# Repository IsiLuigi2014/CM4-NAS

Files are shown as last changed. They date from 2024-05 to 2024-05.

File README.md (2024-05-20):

# CM4 NAS Board [UNMAINTAINED | UNTESTED]

This is a fork from the CM4 NAS Board Project from mebs, added 12V power circuitry only to power it. UNTESTED

This Compute Module 4 carrier board design exposes a subset of the CM4's interfaces, including its single PCIe 2.0 lane to accept an external SATA controller card.
This design is based off of the official Raspberry Pi Foundation's CM4 IO board (the KiCad project is available on the [IO board official page](https://www.raspberrypi.org/products/compute-module-4-io-board/?resellerType=home)). Removed the IO that was less relevant for a NAS and rearranged the remaining interfaces for a smaller footprint that would fit within the width of a standard 3.5" hard drive.

The board was intentionally kept simple to limit mistakes as this is my first ever attempt at designing a PCB and I have no background in electronics, so all the power management is left to external power supplies and buck converters. It's important to use good quality regulated power supplies with this board as it offers no protection other than what is built into the CM4.

Also made 3D printed enclosure for the final product. Design available here: https://www.thingiverse.com/thing:4820662 (Properly not compertablie anymore since made board bigger for 12v power only)

Feel free to explore the discussion section of this repo to share ideas.

[Latest Reddit post here.](https://www.reddit.com/r/raspberry_pi/comments/mkbxss/cm4_custom_nas_complete/)



##### Table of Contents
- [Software](#software)
- [Board IO](#board-io)
  * [CM4 IO Breakout](#cm4-io-breakout)
  * [Other Connections on the Board](#other-connections-on-the-board)
- [PCB Assembly](#pcb-assembly)
  * [Manufacturing](#manufacturing)
  * [Required Parts](#required-parts)
  * [Building](#building)
- [Pinout](#pinout)
- [Revision History](#revision-history)

# Software
For the software part of this project, I highly recommend [Jeff Geerling's repo](https://github.com/geerlingguy/raspberry-pi-pcie-devices/issues), where he documented similar endeavors, but you will likely have to recompile the kernel after enabling some modules to be able to use a PCIe SATA controller.

Don't hesitate to ask questions in the Discussion tab of this repo.

# Board IO
## CM4 IO Breakout
The interfaces the board forwards from the CM4 are the following:
- **PCIe x1 Gen2**: Good old PCIe 2.0, nothing special about it... if not that it's on a Raspberry Pi.
- **Ethernet**: To reduce the number of components on the board and make assembly easier, a MagJack is used instead of a simple RJ45 connector. I had to look this up when I saw it in the IO board design, but a MagJack seems to be simply an RJ45 connector with integrated filters to help with signal integrity. Footprint is specific to the part listed bellow.
- **Single master/slave USB, selected with jumper**: A USB type A port to plug a keyboard, a flash drive, a hub, or whatever you want to use as a USB slave to the CM4. Footprint is not standard so make sure it fits yours if you manufacture the PCB. Can also be used in slave mode (CM4 as slave). You would use this to program the eMMC with you computer. This connection taps into the same single USB bus the CM4 has to offer, but when this is used, the VCC input from the master signals that the CM4 should behave as a slave. Currently the footprint for this is a simple 5 pin header.
- **Full size HDMI**:  Mostly for debugging purposes, hooked to the HDMI0 output of the CM4.
- **I²C**: This is marked "OLED" on the board because this was the intended use, but you can use this to slave any I²C device to the CM4. Five-pin JST connector footprint (fits simple headers too).
- **Single wire temperature sensor**: Marked "Temp_sensor" on the board, hooked to GPIO_4 on the CM4. I would recommend using it for a temp sensor near the SATA controller because they can get really hot and control the fan (see bellow) based on that.
- **9 GPIOs**: General purpose IO header, including Gnd, 3V3 and 5V pins.
- **Configuration headers**: nRPIBOOT, EEPROM_nWP, AIN1, SYNC_IN, SYNC_OUT, TV_OUT, GLOBAL_EN, RUN_PG, WL_nDis, BT_nDis. The pinout is detailed on the board.

## Other Connections on the Board
Other than relaying the compute module's IOs, the board adds other connections, mainly for power.
- **Fan control**: The board expects a dedicated PWM fan controller IC (see part list). Its output is routed to this JST connector (or your typical PWM fan connector) marked "Fan_PWM" on the board.
- **USB selection headers**: To avoid needing a USB MUX on board, this header should be used with a jumper to select if you want to use the USB bus as master or as slave.
- **HDDs power**: Labeled "SATA_PWR". This is the power rail for the hard drives.

# PCB Assembly
## Manufacturing
There is a *Fab* folder at the repo's root. This folder contains all the files that you need to order PCBs from a manufacturer. You will find in the folder a Fab_rev1.4.zip archive that is all you need to order from JLC PCB. This is the latest version and the one I have been running for months now.

## Required Parts
Other than the standard caps and resistors, here are the components you will need if you want to assemble the board:
- **High density connectors** ([digikey](https://www.digikey.ca/en/products/detail/hirose-electric-co-ltd/DF40C-100DS-0.4V%2851%29/1969495), [LCSC](https://lcsc.com/product-detail/Mezzanine-Connectors-Board-to-Board_HRS-Hirose-DF40C-100DS-0-4V-51_C597931.html)): You will need these to connect the CM4 to the board. They can be very daunting, but I found [this video](https://www.youtube.com/watch?v=eukcrFc18P4) of someone neatly soldering them with a hot air gun. When I finaly got to try it, I was surprise at how doable it was.
- **Ethernet** ([digikey](https://www.digikey.de/de/products/detail/abracon-llc/ARJM11C7-502-AB-ER2-T/7675199)): Switch from the expensive one to a cheaper model.
- **Fan controller** ([digikey](https://www.digikey.ca/en/products/detail/microchip-technology/EMC2301-1-ACZL-TR/4696431), [LCSC](https://lcsc.com/product-detail/_MICROCHIP_EMC2301-1-ACZL-TR_EMC2301-1-ACZL-TR_C148036.html)): This chip is the exact same one that is on the official IO board and it's controlled by the CM4 through I²C.
- **ESD sinks** ([digikey](https://www.digikey.ca/en/products/detail/texas-instruments/TPD4EUSB30DQAR/2503671), [LCSC](https://lcsc.com/product-detail/Diodes-ESD_Texas-Instruments-TPD4EUSB30DQAR_C90627.html)): They are optional in my (very uninformed) opinion. I think they were included on the IO board for POE applications mostly.
- **Signal buffer** ([digikey](https://www.digikey.ca/en/products/detail/diodes-incorporated/74LVC1G07SE-7/2356550), [LCSC](https://lcsc.com/product-detail/Logic-Buffers-Drivers-Receivers-Transceivers_Diodes-Incorporated-74LVC1G07SE-7_C67531.html)): Used for the power LED and to buffer RUN_PG signal to be able to wake the CM4 from a sleep state.
- **HDMI connector** ([LCSC](https://lcsc.com/product-detail/Audio-Video-Connectors_SOFNG-HDMI-019S_C111617.html)): Basic full size HDMI connector.

## Building
To build the board, you will need a soldering iron and a hot air gun (or a reflow oven). I would recommend starting with the Hirose high density connectors as they are without a doubt the hardest part. [This video](https://www.youtube.com/watch?v=eukcrFc18P4) I referred to earlier is a good starting point, it makes for a fine tutorial.
It only took a couple tries before I could get a decent result (image from microscope at around 50-60x):



Once the HD connectors are in place, you can move on to the ESD sinks. They are very small and can also be daunting, but soldering them turned out to be easier than expected.
The trick is to put as little solder paste as possible and the chips will naturally be pulled in place by the solder's surface tension.



The rest of the parts should be fairly easy to solder with a standard iron.

# Pinout
**Not up to date anymore.**

  

# Revision History
- **1**: Initial version
- **1.1**: Fixed wrong footprint for fan controller
- **1.2**: Changed the USB select headers for a simpler solution with a single jumper
- **1.3**: Replaced the HDMI header by a full size HDMI female connector, exposed 9 GPIOs, inverted polarity back for PCIe Tx/Rx signals and added a power LED.
- **1.4**: Add pin to OLED connector for button, use SMD caps and LEDs, more info on silkscreen and fixed some traces.
- **1.5**: Added support for 12v power only

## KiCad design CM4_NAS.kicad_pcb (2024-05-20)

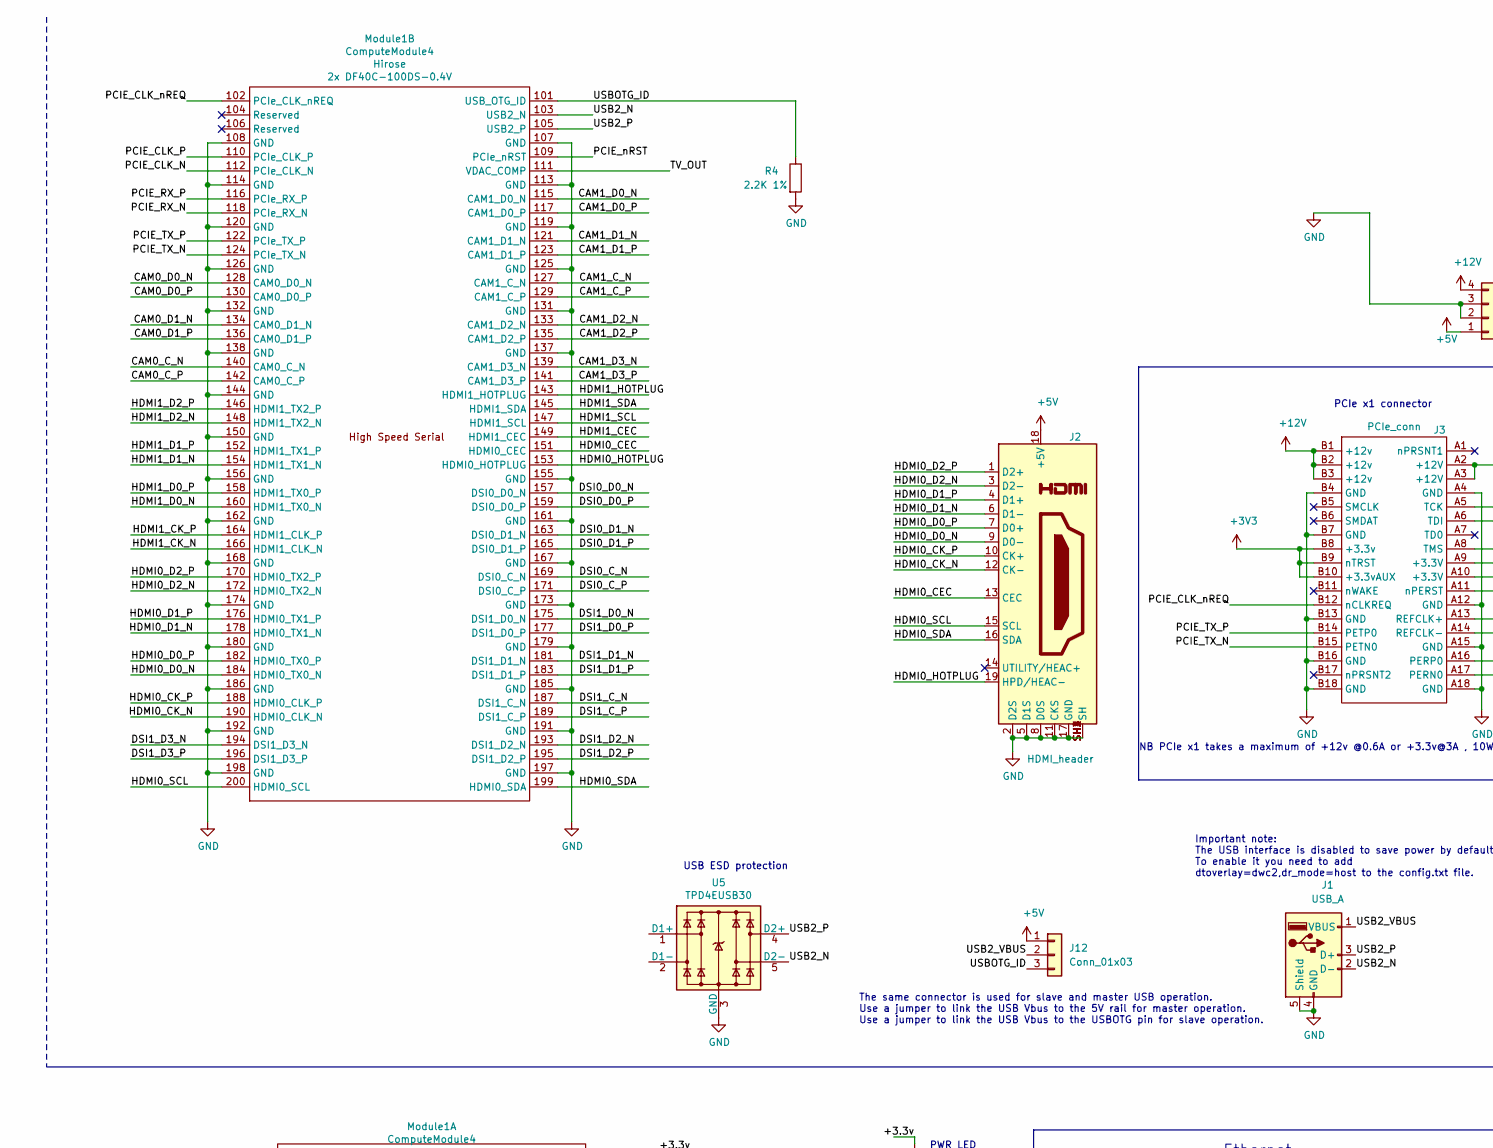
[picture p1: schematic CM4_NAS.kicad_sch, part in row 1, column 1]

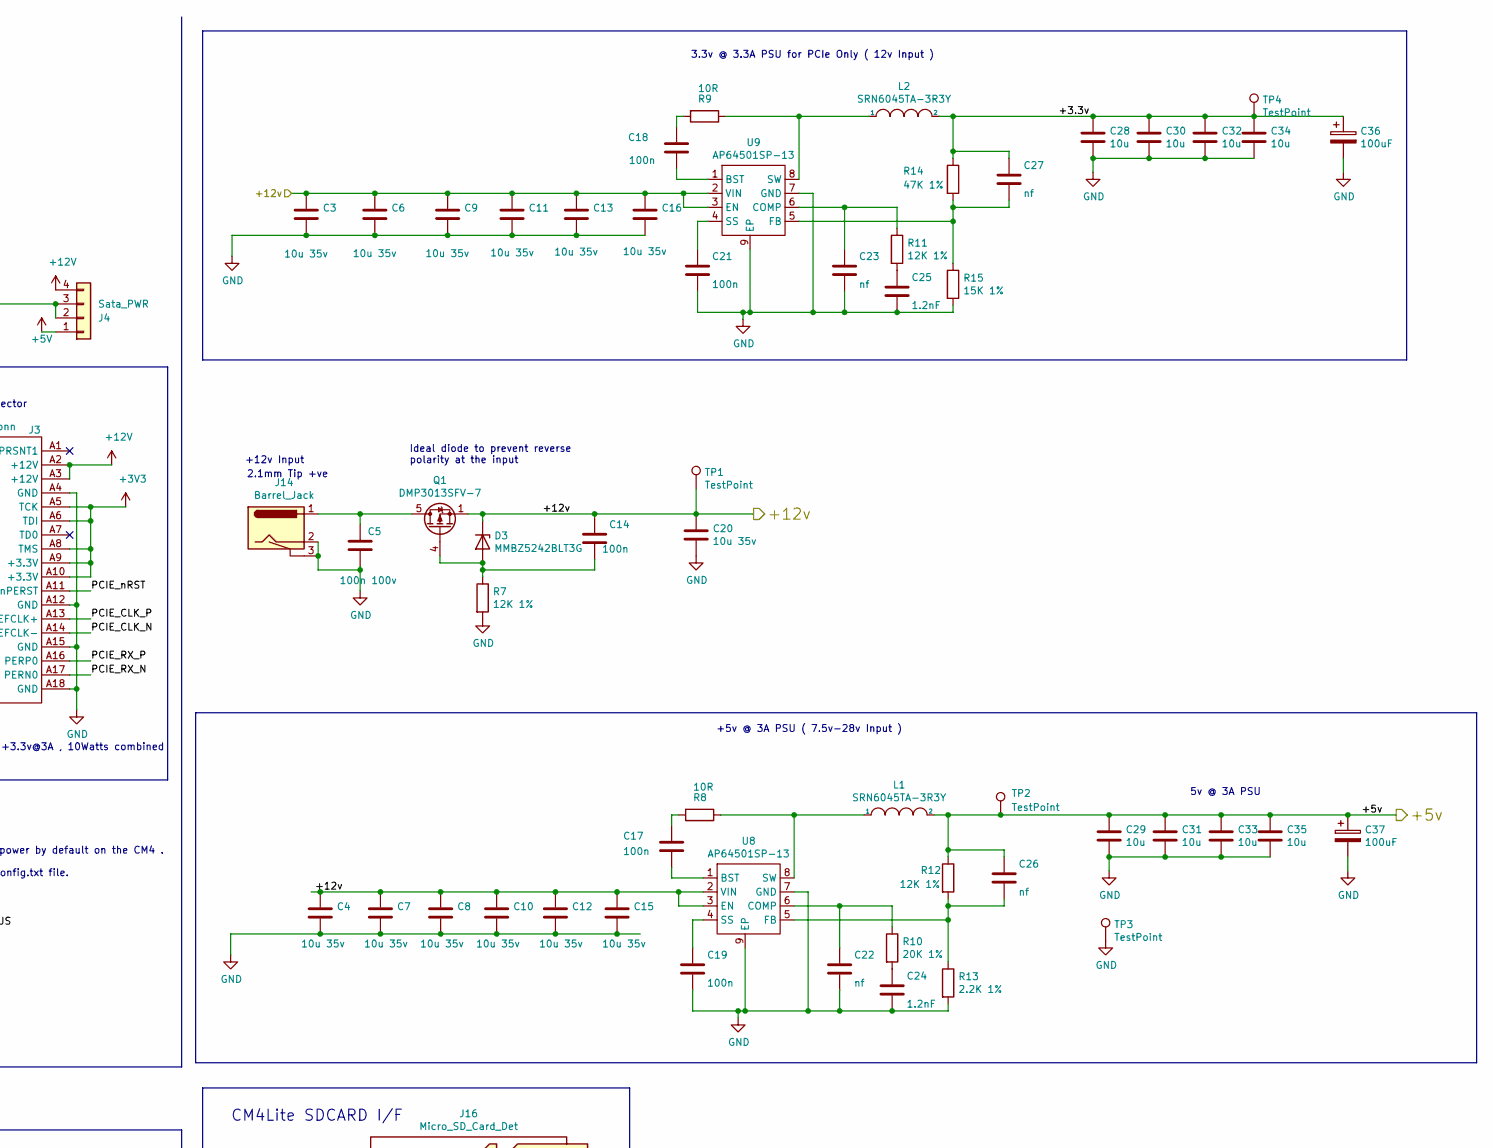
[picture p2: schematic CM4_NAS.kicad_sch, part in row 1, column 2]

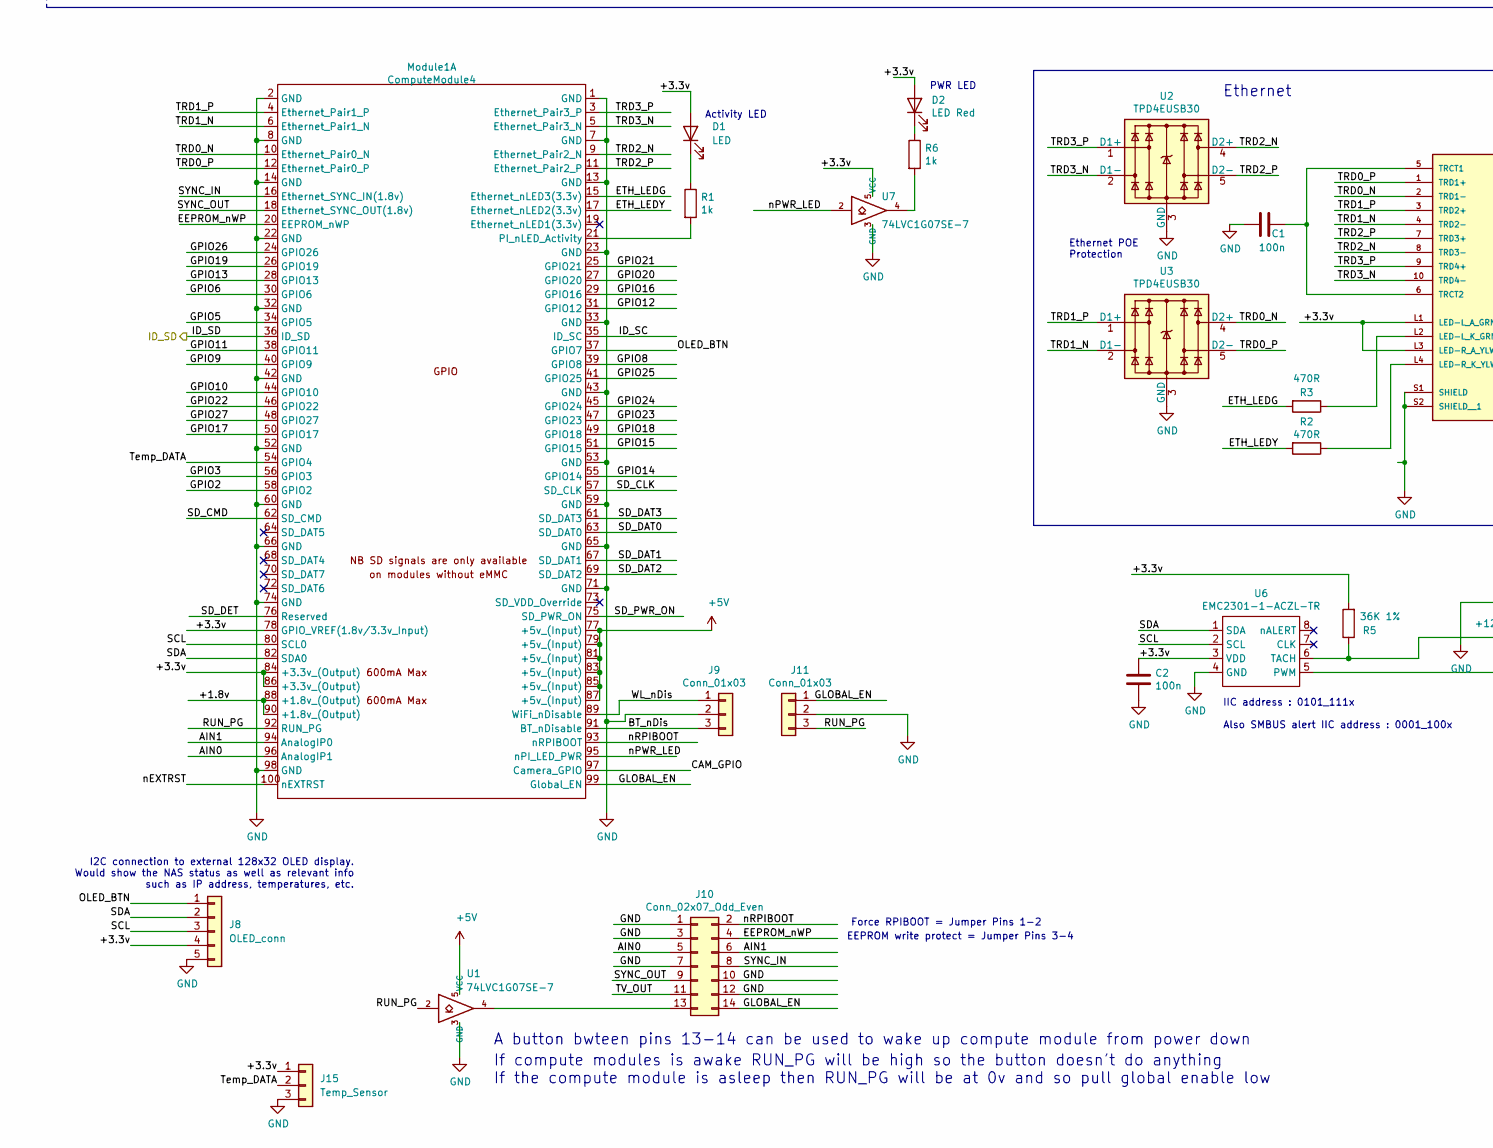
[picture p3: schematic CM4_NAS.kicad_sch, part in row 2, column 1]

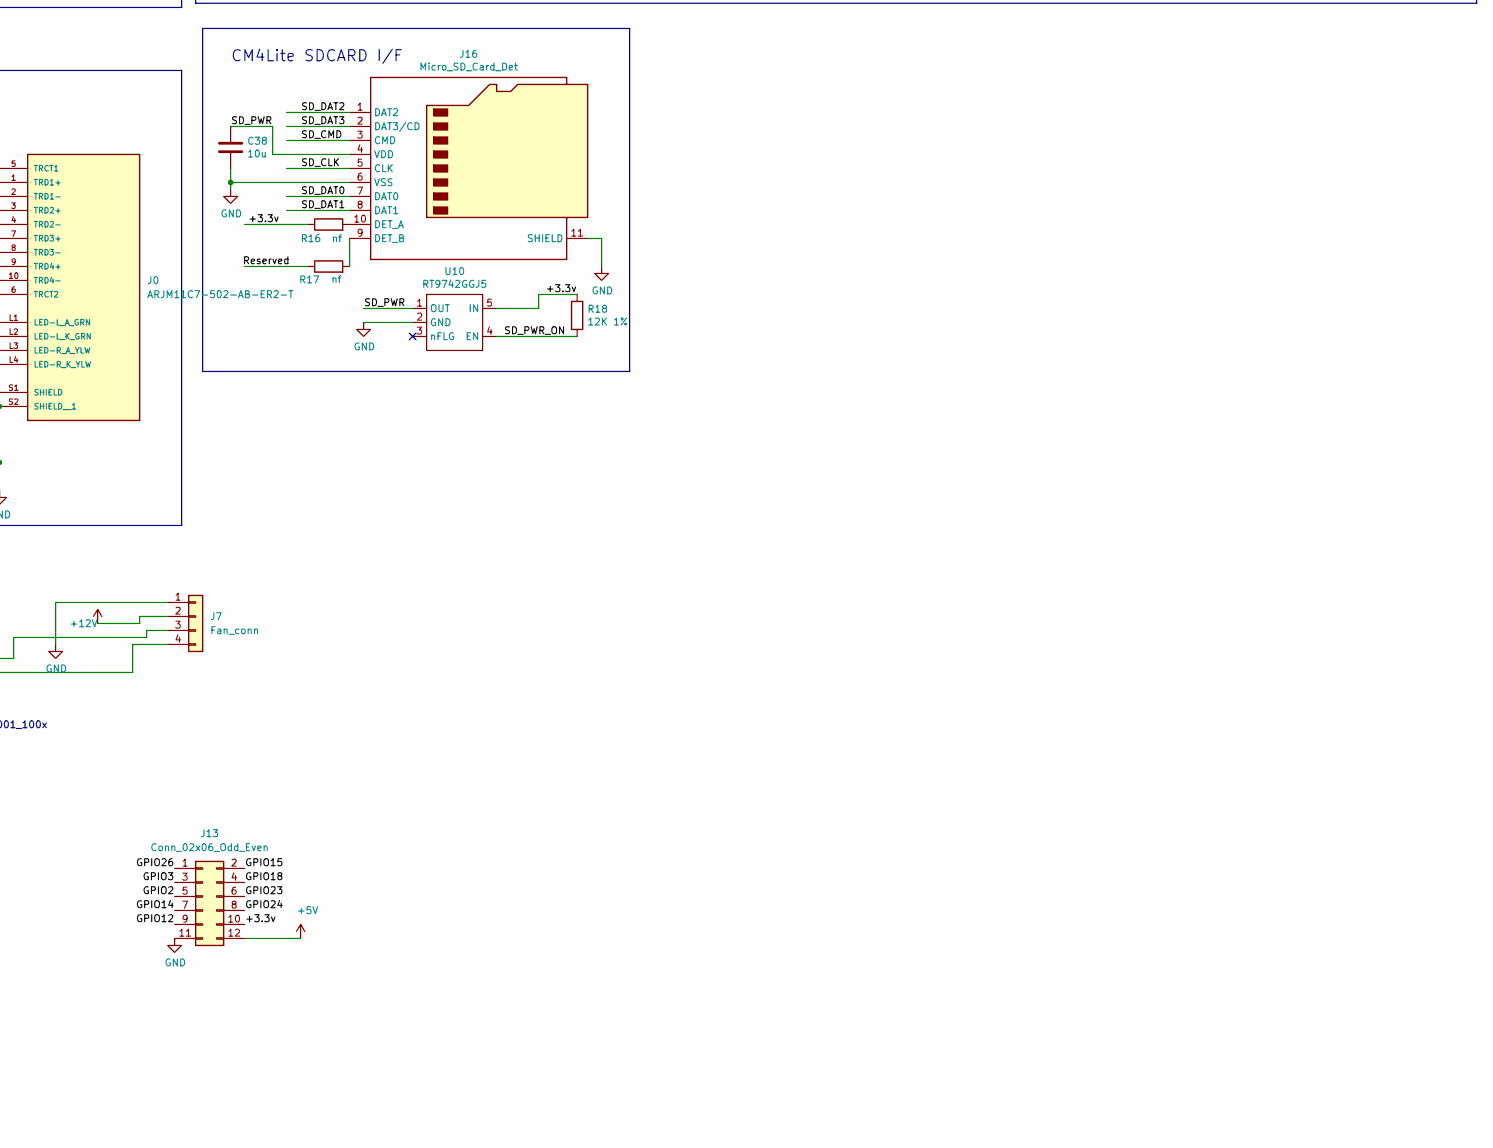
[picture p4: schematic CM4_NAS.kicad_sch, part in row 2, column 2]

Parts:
C1, C2: 100n; C_0805_2012Metric_Pad1.18x1.45mm_HandSolder
C3, C4, C6, C7, C8, C9, C10, C11, C12, C13, C15, C16, C20: 10u 35v; C_0805_2012Metric; Part Description 10uF 10% or 20% 35V Ceramic Capacitor X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
C5: 100n 100v; C_0402_1005Metric; Part Description 0.1uF 10% 100V Ceramic Capacitor X5R 04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
C14, C17, C18, C19, C21: 100n; C_0402_1005Metric; Part Description 0.1uF 10% 16V Ceramic Capacitor X7R 040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
C22, C23: nf; C_0402_1005Metric
C24, C25: 1.2nF; C_0402_1005Metric; Part Description 1200pF 10% 10V Ceramic Capacitor X5R 04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
C26: nf; C_0402_1005Metric; Part Description 220 pF, 50 V, 0402 [1005 Metric], ± 5%,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
C27: nf; C_0402_1005Metric; Part Description 27pF 5% 50V Ceramic Capacitor C0G, NP0 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
C28, C29, C30, C31, C32, C33, C34, C35, C38: 10u; C_0805_2012Metric; Part Description 10uF 10% 10V Ceramic Capacitor X7R 0805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
C36, C37: 100uF; CP_EIA-7343-31_Kemet-D; Part Description Capacitor, SP-Cap, 100u, 6.3V, 15mR ESR
D1: LED; LED_0805_2012Metric_Pad1.15x1.40mm_HandSolder
D2: LED Red; LED_0805_2012Metric_Pad1.15x1.40mm_HandSolder
D3: MMBZ5242BLT3G; D_SOT-23_ANK; Part Description Zener Diode 12V 225mW 5% Surface Mount 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
J0: ARJM11C7-502-AB-ER2-T; ABRACON_ARJM11C7-502-AB-ER2-T; PARTREV 04.22.2019
J1: USB_A; USB_A_Vertical
J2: HDMI_header; HDMI EDAC 690-019-298-412
J3: PCIe_conn; PCIex1-36; Part Description PCI Express/PCI Connectors PCIE THROUGH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
J4: Sata_PWR; JST_XH_B4B-XH-A_1x04_P2.50mm_Vertical
J7: Fan_conn; JST_XH_B4B-XH-A_1x04_P2.50mm_Vertical
J8: OLED_conn; JST_XH_B5B-XH-A_1x05_P2.50mm_Vertical
J9, J11: Conn_01x03; PinHeader_1x03_P2.54mm_Vertical; Part Description 3pin 0.1" connector
J10: Conn_02x07_Odd_Even; PinHeader_2x07_P2.54mm_Vertical; Part Description PinHeader_2x07_P2.54mm_Vertical
J12: Conn_01x03; PinHeader_1x03_P2.54mm_Vertical
J13: Conn_02x06_Odd_Even; PinHeader_2x06_P2.54mm_Vertical
J14: Barrel_Jack; BarrelJack_Horizontal; Part Description DC Power Connectors PCB 2.1MM
J15: Temp_Sensor; PinSocket_1x03_P2.54mm_Vertical
J16: Micro_SD_Card_Det; SDCARD_MOLEX_503398-1892; Part Description 9 (8 + 1) Position Card Connector micro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
L1, L2: SRN6045TA-3R3Y; L_Bourns_SRN6045TA; Part Description 3.3µH Semi-Shielded Wirewound Inductor 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
Module1: ComputeModule4; Raspberry-Pi-4-Compute-Module; Part Description 100 Position Connector Receptacle, Cent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
Q1: DMP3013SFV-7; Diodes_PowerDI3333-8; Part Description DMP3013SFV-7 - Power MOSFET, P Channel,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
R1, R6: 1k; R_0402_1005Metric; Part Description Resistor 1K M1005 1% 63mW
R2: 470R; R_0402_1005Metric
R3: 470R; R_0402_1005Metric; Part Description Resistor 470R M1005 1% 63mW
R4: 2.2K 1%; R_0402_1005Metric
R5: 36K 1%; R_0402_1005Metric
R7, R11, R12, R18: 12K 1%; R_0402_1005Metric; Part Description Resistor 12K M1005 1% 63mW
R8, R9: 10R; R_0402_1005Metric; Part Description Resistor 10R M1005 1% 63mW
R10: 20K 1%; R_0402_1005Metric; Part Description Resistor 20K M1005 1% 63mW
R13: 2.2K 1%; R_0402_1005Metric; Part Description Resistor 2.2K M1005 1% 63mW
R14: 47K 1%; R_0402_1005Metric; Part Description Resistor 47K M1005 1% 63mW
R15: 15K 1%; R_0402_1005Metric; Part Description Resistor 15K M1005 1% 63mW
R16, R17: nf; R_0402_1005Metric; Part Description Resistor 1K M1005 1% 63mW
TP1, TP2, TP3, TP4: TestPoint; TestPoint_Pad_2.0x2.0mm
U1, U7: 74LVC1G07SE-7; SOT-353_SC-70-5; Part Description Buffer, Non-Inverting 1 Element 1 Bit p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
U2, U3, U5: TPD4EUSB30; USON-10_2.5x1.0mm_P0.5mm; Part Description Quad TVS diode for high speed signals (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
U6: EMC2301-1-ACZL-TR; MSOP-8_3x3mm_P0.65mm; Part Description Motor Driver PWM 8-MSOP
U8, U9: AP64501SP-13; SOIC-8-1EP_3.9x4.9mm_P1.27mm_EP2.95x4.9mm_Mask2.71x3.4mm_Th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; Part Description Buck Switching Regulator IC Positive Ad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
U10: RT9742GGJ5; SOT-23-5; Part Description Power Switch/Driver 1:1 N-Channel 1A TS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

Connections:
+3V3: J3.A5 (TCK), J3.A6 (TDI), J3.A8 (TMS), J3.A9 (+3.3V), J3.A10 (+3.3V), J3.B8 (+3.3v), J3.B9 (nTRST), J3.B10 (+3.3vAUX)
+5V: J2.18 (+5V), J4.1, J12.1, J13.12, Module1.77 (+5v_(Input)), Module1.79 (+5v_(Input)), Module1.81 (+5v_(Input)), Module1.83 (+5v_(Input)), Module1.85 (+5v_(Input)), Module1.87 (+5v_(Input)), U1.5 (VCC)
+12V: J3.A2 (+12V), J3.A3 (+12V), J3.B1 (+12v), J3.B2 (+12v), J3.B3 (+12v), J4.4, J7.2
/+1.8v: Module1.88 (+1.8v_(Output)), Module1.90 (+1.8v_(Output))
/+3.3v: C2.1, C27.1, C28.1, C30.1, C32.1, C34.1, C36.1, D1.2 (A), D2.2 (A), J0.L1 (LED-L_A_GRN), J0.L3 (LED-R_A_YLW), J8.4, J13.10, J15.1, L2.2, Module1.78 (GPIO_VREF(1.8v/3.3v_Input)), Module1.84 (+3.3v_(Output)), Module1.86 (+3.3v_(Output)), R5.2, R14.1, R16.1, R18.1, TP4.1, U6.3 (VDD), U7.5 (VCC), U10.5 (IN)
/+5v: C26.1, C29.1, C31.1, C33.1, C35.1, C37.1, L1.2, R12.1, TP2.1
/+12v: C3.1, C4.1, C6.1, C7.1, C8.1, C9.1, C10.1, C11.1, C12.1, C13.1, C14.1, C15.1, C16.1, C20.1, D3.1 (K), Q1.1 (S), Q1.2 (S), Q1.3 (S), TP1.1, U8.2 (VIN), U8.3 (EN), U9.2 (VIN), U9.3 (EN)
/AIN0: J10.5, Module1.96 (AnalogIP1)
/AIN1: J10.6, Module1.94 (AnalogIP0)
/BT_nDis: J9.3, Module1.91 (BT_nDisable)
/CAM0_C_N: Module1.140 (CAM0_C_N)
/CAM0_C_P: Module1.142 (CAM0_C_P)
/CAM0_D0_N: Module1.128 (CAM0_D0_N)
/CAM0_D0_P: Module1.130 (CAM0_D0_P)
/CAM0_D1_N: Module1.134 (CAM0_D1_N)
/CAM0_D1_P: Module1.136 (CAM0_D1_P)
/CAM1_C_N: Module1.127 (CAM1_C_N)
/CAM1_C_P: Module1.129 (CAM1_C_P)
/CAM1_D0_N: Module1.115 (CAM1_D0_N)
/CAM1_D0_P: Module1.117 (CAM1_D0_P)
/CAM1_D1_N: Module1.121 (CAM1_D1_N)
/CAM1_D1_P: Module1.123 (CAM1_D1_P)
/CAM1_D2_N: Module1.133 (CAM1_D2_N)
/CAM1_D2_P: Module1.135 (CAM1_D2_P)
/CAM1_D3_N: Module1.139 (CAM1_D3_N)
/CAM1_D3_P: Module1.141 (CAM1_D3_P)
/CAM_GPIO: Module1.97 (Camera_GPIO)
/DSI0_C_N: Module1.169 (DSI0_C_N)
/DSI0_C_P: Module1.171 (DSI0_C_P)
/DSI0_D0_N: Module1.157 (DSI0_D0_N)
/DSI0_D0_P: Module1.159 (DSI0_D0_P)
/DSI0_D1_N: Module1.163 (DSI0_D1_N)
/DSI0_D1_P: Module1.165 (DSI0_D1_P)
/DSI1_C_N: Module1.187 (DSI1_C_N)
/DSI1_C_P: Module1.189 (DSI1_C_P)
/DSI1_D0_N: Module1.175 (DSI1_D0_N)
/DSI1_D0_P: Module1.177 (DSI1_D0_P)
/DSI1_D1_N: Module1.181 (DSI1_D1_N)
/DSI1_D1_P: Module1.183 (DSI1_D1_P)
/DSI1_D2_N: Module1.193 (DSI1_D2_N)
/DSI1_D2_P: Module1.195 (DSI1_D2_P)
/DSI1_D3_N: Module1.194 (DSI1_D3_N)
/DSI1_D3_P: Module1.196 (DSI1_D3_P)
/EEPROM_nWP: J10.4, Module1.20 (EEPROM_nWP)
/ETH_LEDG: Module1.15 (Ethernet_nLED3(3.3v)), R3.2
/ETH_LEDY: Module1.17 (Ethernet_nLED2(3.3v)), R2.2
/GLOBAL_EN: J10.14, J11.1, Module1.99 (Global_EN)
/GPIO2: J13.5, Module1.58 (GPIO2)
/GPIO3: J13.3, Module1.56 (GPIO3)
/GPIO5: Module1.34 (GPIO5)
/GPIO6: Module1.30 (GPIO6)
/GPIO8: Module1.39 (GPIO8)
/GPIO9: Module1.40 (GPIO9)
/GPIO10: Module1.44 (GPIO10)
/GPIO11: Module1.38 (GPIO11)
/GPIO12: J13.9, Module1.31 (GPIO12)
/GPIO13: Module1.28 (GPIO13)
/GPIO14: J13.7, Module1.55 (GPIO14)
/GPIO15: J13.2, Module1.51 (GPIO15)
/GPIO16: Module1.29 (GPIO16)
/GPIO17: Module1.50 (GPIO17)
/GPIO18: J13.4, Module1.49 (GPIO18)
/GPIO19: Module1.26 (GPIO19)
/GPIO20: Module1.27 (GPIO20)
/GPIO21: Module1.25 (GPIO21)
/GPIO22: Module1.46 (GPIO22)
/GPIO23: J13.6, Module1.47 (GPIO23)
/GPIO24: J13.8, Module1.45 (GPIO24)
/GPIO25: Module1.41 (GPIO25)
/GPIO26: J13.1, Module1.24 (GPIO26)
/GPIO27: Module1.48 (GPIO27)
/HDMI0_CEC: J2.13 (CEC), Module1.151 (HDMI0_CEC)
/HDMI0_CK_N: J2.12 (CK-), Module1.190 (HDMI0_CLK_N)
/HDMI0_CK_P: J2.10 (CK+), Module1.188 (HDMI0_CLK_P)
/HDMI0_D0_N: J2.9 (D0-), Module1.184 (HDMI0_TX0_N)
/HDMI0_D0_P: J2.7 (D0+), Module1.182 (HDMI0_TX0_P)
/HDMI0_D1_N: J2.6 (D1-), Module1.178 (HDMI0_TX1_N)
/HDMI0_D1_P: J2.4 (D1+), Module1.176 (HDMI0_TX1_P)
/HDMI0_D2_N: J2.3 (D2-), Module1.172 (HDMI0_TX2_N)
/HDMI0_D2_P: J2.1 (D2+), Module1.170 (HDMI0_TX2_P)
/HDMI0_HOTPLUG: J2.19 (HPD/HEAC-), Module1.153 (HDMI0_HOTPLUG)
/HDMI0_SCL: J2.15 (SCL), Module1.200 (HDMI0_SCL)
/HDMI0_SDA: J2.16 (SDA), Module1.199 (HDMI0_SDA)
/HDMI1_CEC: Module1.149 (HDMI1_CEC)
/HDMI1_CK_N: Module1.166 (HDMI1_CLK_N)
/HDMI1_CK_P: Module1.164 (HDMI1_CLK_P)
/HDMI1_D0_N: Module1.160 (HDMI1_TX0_N)
/HDMI1_D0_P: Module1.158 (HDMI1_TX0_P)
/HDMI1_D1_N: Module1.154 (HDMI1_TX1_N)
/HDMI1_D1_P: Module1.152 (HDMI1_TX1_P)
/HDMI1_D2_N: Module1.148 (HDMI1_TX2_N)
/HDMI1_D2_P: Module1.146 (HDMI1_TX2_P)
/HDMI1_HOTPLUG: Module1.143 (HDMI1_HOTPLUG)
/HDMI1_SCL: Module1.147 (HDMI1_SCL)
/HDMI1_SDA: Module1.145 (HDMI1_SDA)
/ID_SC: Module1.35 (ID_SC)
/ID_SD: Module1.36 (ID_SD)
/OLED_BTN: J8.1, Module1.37 (GPIO7)
/PCIE_CLK_N: J3.A14 (REFCLK-), Module1.112 (PCIe_CLK_N)
/PCIE_CLK_P: J3.A13 (REFCLK+), Module1.110 (PCIe_CLK_P)
/PCIE_CLK_nREQ: J3.B12 (nCLKREQ), Module1.102 (PCIe_CLK_nREQ)
/PCIE_RX_N: J3.A17 (PERN0), Module1.118 (PCIe_RX_N)
/PCIE_RX_P: J3.A16 (PERP0), Module1.116 (PCIe_RX_P)
/PCIE_TX_N: J3.B15 (PETN0), Module1.124 (PCIe_TX_N)
/PCIE_TX_P: J3.B14 (PETP0), Module1.122 (PCIe_TX_P)
/PCIE_nRST: J3.A11 (nPERST), Module1.109 (PCIe_nRST)
/RUN_PG: J11.3, Module1.92 (RUN_PG), U1.2
/SCL: J8.3, Module1.80 (SCL0), U6.2 (SCL)
/SDA: J8.2, Module1.82 (SDA0), U6.1 (SDA)
/SD_CLK: J16.5 (CLK), Module1.57 (SD_CLK)
/SD_CMD: J16.3 (CMD), Module1.62 (SD_CMD)
/SD_DAT0: J16.7 (DAT0), Module1.63 (SD_DAT0)
/SD_DAT1: J16.8 (DAT1), Module1.67 (SD_DAT1)
/SD_DAT2: J16.1 (DAT2), Module1.69 (SD_DAT2)
/SD_DAT3: J16.2 (DAT3/CD), Module1.61 (SD_DAT3)
/SD_DET: Module1.76 (Reserved)
/SD_PWR_ON: Module1.75 (SD_PWR_ON), R18.2, U10.4 (EN)
/SYNC_IN: J10.8, Module1.16 (Ethernet_SYNC_IN(1.8v))
/SYNC_OUT: J10.9, Module1.18 (Ethernet_SYNC_OUT(1.8v))
/TRD0_N: J0.2 (TRD1-), Module1.10 (Ethernet_Pair0_N), U3.4 (D2+), U3.7
/TRD0_P: J0.1 (TRD1+), Module1.12 (Ethernet_Pair0_P), U3.5 (D2-), U3.6
/TRD1_N: J0.4 (TRD2-), Module1.6 (Ethernet_Pair1_N), U3.2 (D1-), U3.9
/TRD1_P: J0.3 (TRD2+), Module1.4 (Ethernet_Pair1_P), U3.1 (D1+), U3.10
/TRD2_N: J0.8 (TRD3-), Module1.9 (Ethernet_Pair2_N), U2.4 (D2+), U2.7
/TRD2_P: J0.7 (TRD3+), Module1.11 (Ethernet_Pair2_P), U2.5 (D2-), U2.6
/TRD3_N: J0.10 (TRD4-), Module1.5 (Ethernet_Pair3_N), U2.2 (D1-), U2.9
/TRD3_P: J0.9 (TRD4+), Module1.3 (Ethernet_Pair3_P), U2.1 (D1+), U2.10
/TV_OUT: J10.11, Module1.111 (VDAC_COMP)
/Temp_DATA: J15.2, Module1.54 (GPIO4)
/USB2_N: J1.2 (D-), Module1.103 (USB2_N), U5.5 (D2-), U5.6
/USB2_P: J1.3 (D+), Module1.105 (USB2_P), U5.4 (D2+), U5.7
/USB2_VBUS: J1.1 (VBUS), J12.2
/USBOTG_ID: J12.3, Module1.101 (USB_OTG_ID), R4.1
/WL_nDis: J9.1, Module1.89 (WiFi_nDisable)
/nEXTRST: Module1.100 (nEXTRST)
/nPWR_LED: Module1.95 (nPI_LED_PWR), U7.2
/nRPIBOOT: J10.2, Module1.93 (nRPIBOOT)
GND: C1.2, C2.2, C3.2, C4.2, C5.2, C6.2, C7.2, C8.2, C9.2, C10.2, C11.2, C12.2, C13.2, C15.2, C16.2, C19.2, C20.2, C21.2, C22.2, C23.2, C24.2, C25.2, C28.2, C29.2, C30.2, C31.2, C32.2, C33.2, C34.2, C35.2, C36.2, C37.2, C38.2, J0.S1 (SHIELD), J0.S2 (SHIELD__1), J1.4 (GND), J1.5 (Shield), J2.2 (D2S), J2.5 (D1S), J2.8 (D0S), J2.11 (CKS), J2.17 (GND), J2.SH1 (SH), J2.SH2 (SH), J2.SH3 (SH), J2.SH4 (SH), J3.A4 (GND), J3.A12 (GND), J3.A15 (GND), J3.A18 (GND), J3.B4 (GND), J3.B7 (GND), J3.B13 (GND), J3.B16 (GND), J3.B18 (GND), J4.2, J4.3, J7.1, J8.5, J9.2, J10.1, J10.3, J10.7, J10.10, J10.12, J11.2, J13.11, J14.2, J14.3, J15.3, J16.6 (VSS), J16.11 (SHIELD), Module1.1 (GND), Module1.2 (GND), Module1.7 (GND), Module1.8 (GND), Module1.13 (GND), Module1.14 (GND), Module1.22 (GND), Module1.23 (GND), Module1.32 (GND), Module1.33 (GND), Module1.42 (GND), Module1.43 (GND), Module1.52 (GND), Module1.53 (GND), Module1.59 (GND), Module1.60 (GND), Module1.65 (GND), Module1.66 (GND), Module1.71 (GND), Module1.74 (GND), Module1.98 (GND), Module1.107 (GND), Module1.108 (GND), Module1.113 (GND), Module1.114 (GND), Module1.119 (GND), Module1.120 (GND), Module1.125 (GND), Module1.126 (GND), Module1.131 (GND), Module1.132 (GND), Module1.137 (GND), Module1.138 (GND), Module1.144 (GND), Module1.150 (GND), Module1.155 (GND), Module1.156 (GND), Module1.161 (GND), Module1.162 (GND), Module1.167 (GND), Module1.168 (GND), Module1.173 (GND), Module1.174 (GND), Module1.179 (GND), Module1.180 (GND), Module1.185 (GND), Module1.186 (GND), Module1.191 (GND), Module1.192 (GND), Module1.197 (GND), Module1.198 (GND), R4.2, R7.2, R13.2, R15.2, TP3.1, U1.3 (GND), U2.3 (GND), U2.8 (GND), U3.3 (GND), U3.8 (GND), U5.3 (GND), U5.8 (GND), U6.4 (GND), U7.3 (GND), U8.7 (GND), U8.9 (EP), U9.7 (GND), U9.9 (EP), U10.2 (GND)
unnamed: C17.1, R8.2
unnamed: C18.1, R9.2
unnamed: C24.1, R10.2
unnamed: C25.1, R11.2
unnamed: C38.1, J16.4 (VDD), U10.1 (OUT)
unnamed: D1.1 (K), R1.1
unnamed: D2.1 (K), R6.1
unnamed: C14.2, D3.2 (A), Q1.4 (G), R7.1
unnamed: J0.L2 (LED-L_K_GRN), R3.1
unnamed: J0.L4 (LED-R_K_YLW), R2.1
unnamed: C1.1, J0.5 (TRCT1), J0.6 (TRCT2)
unnamed: J7.3, R5.1, U6.6 (TACH)
unnamed: J7.4, U6.5 (PWM)
unnamed: J10.13, U1.4
unnamed: J16.9 (DET_B), R17.2
unnamed: J16.10 (DET_A), R16.2
unnamed: Module1.21 (PI_nLED_Activity), R1.2
unnamed: C5.1, J14.1, Q1.5 (D)
unnamed: R6.2, U7.4
unnamed: U5.1 (D1+), U5.10
unnamed: U5.2 (D1-), U5.9
unnamed: C17.2, U8.1 (BST)
unnamed: C22.1, R10.1, U8.6 (COMP)
unnamed: C26.2, R12.2, R13.1, U8.5 (FB)
unnamed: C19.1, U8.4 (SS)
unnamed: L1.1, R8.1, U8.8 (SW)
unnamed: C18.2, U9.1 (BST)
unnamed: C23.1, R11.1, U9.6 (COMP)
unnamed: C27.2, R14.2, R15.1, U9.5 (FB)
unnamed: C21.1, U9.4 (SS)
unnamed: L2.1, R9.1, U9.8 (SW)

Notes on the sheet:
5v @ 3A PSU
+5v @ 3A PSU ( 7.5v-28v Input )
A button bwteen pins 13-14 can be used to wake up compute module from power down
Force RPIBOOT = Jumper Pins 1-2
CM4Lite SDCARD I/F
I2C connection to external 128x32 OLED display. Would show the NAS status as well as relevant info such as IP address, temperatures, etc.
The same connector is used for slave and master USB operation. Use a jumper to link the USB Vbus to the 5V rail for master operation. Use a jumper to link the USB Vbus to the USBOTG pin for slave operation.
Ethernet POE Protection
USB ESD protection
IIC address : 0101_111x
If compute modules is awake RUN_PG will be high so the button doesn't do anything If the compute module is asleep then RUN_PG will be at 0v and so pull global enable low
NB PCIe x1 takes a maximum of +12v @0.6A or +3.3v@3A , 10Watts combined
PWR LED
EEPROM write protect = Jumper Pins 3-4
PCIe x1 connector
3.3v @ 3.3A PSU for PCIe Only ( 12v Input )
Also SMBUS alert IIC address : 0001_100x
2.1mm Tip +ve
Activity LED
Important note: The USB interface is disabled to save power by default on the CM4 . To enable it you need to add dtoverlay=dwc2,dr_mode=host to the config.txt file.
Ethernet
+12v Input
Ideal diode to prevent reverse polarity at the input

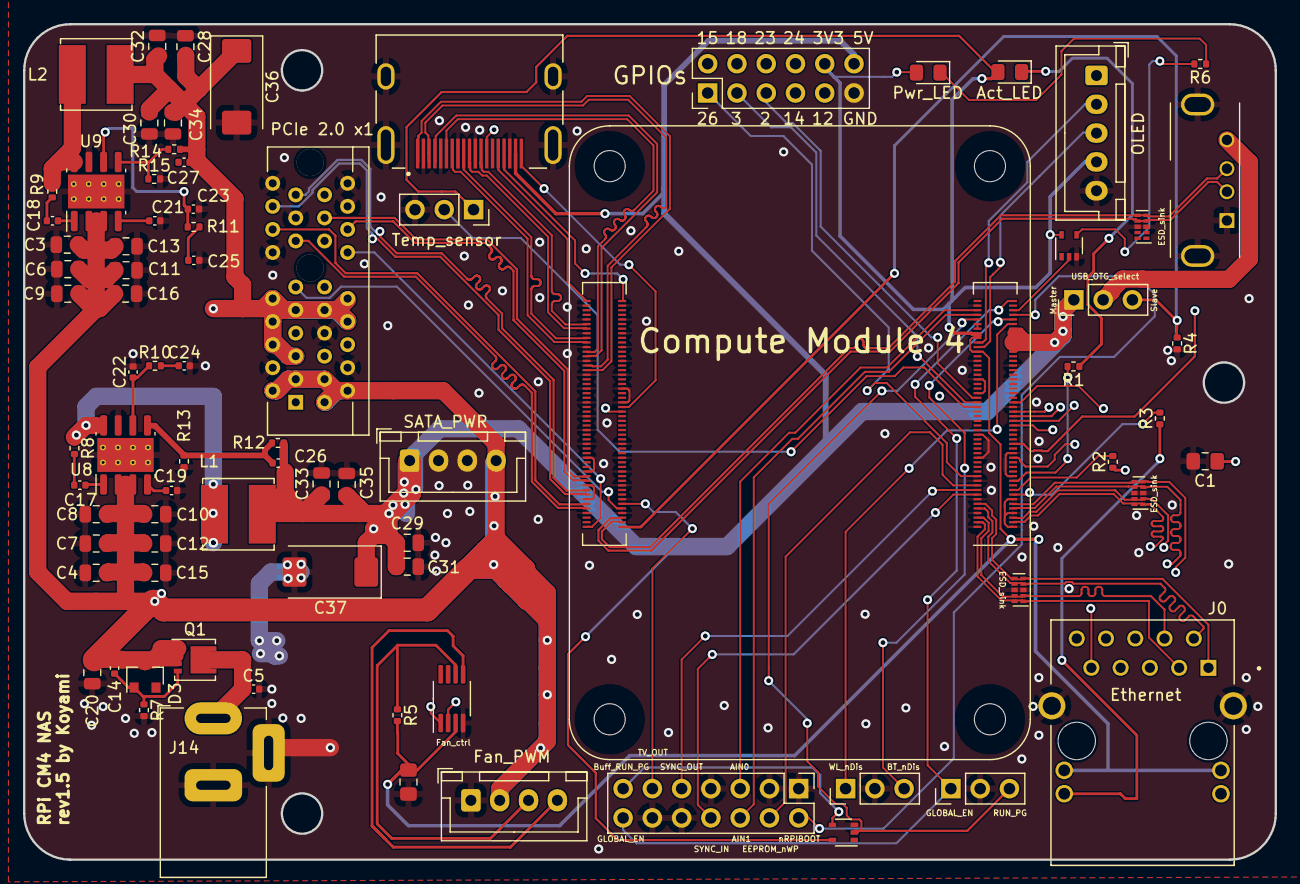
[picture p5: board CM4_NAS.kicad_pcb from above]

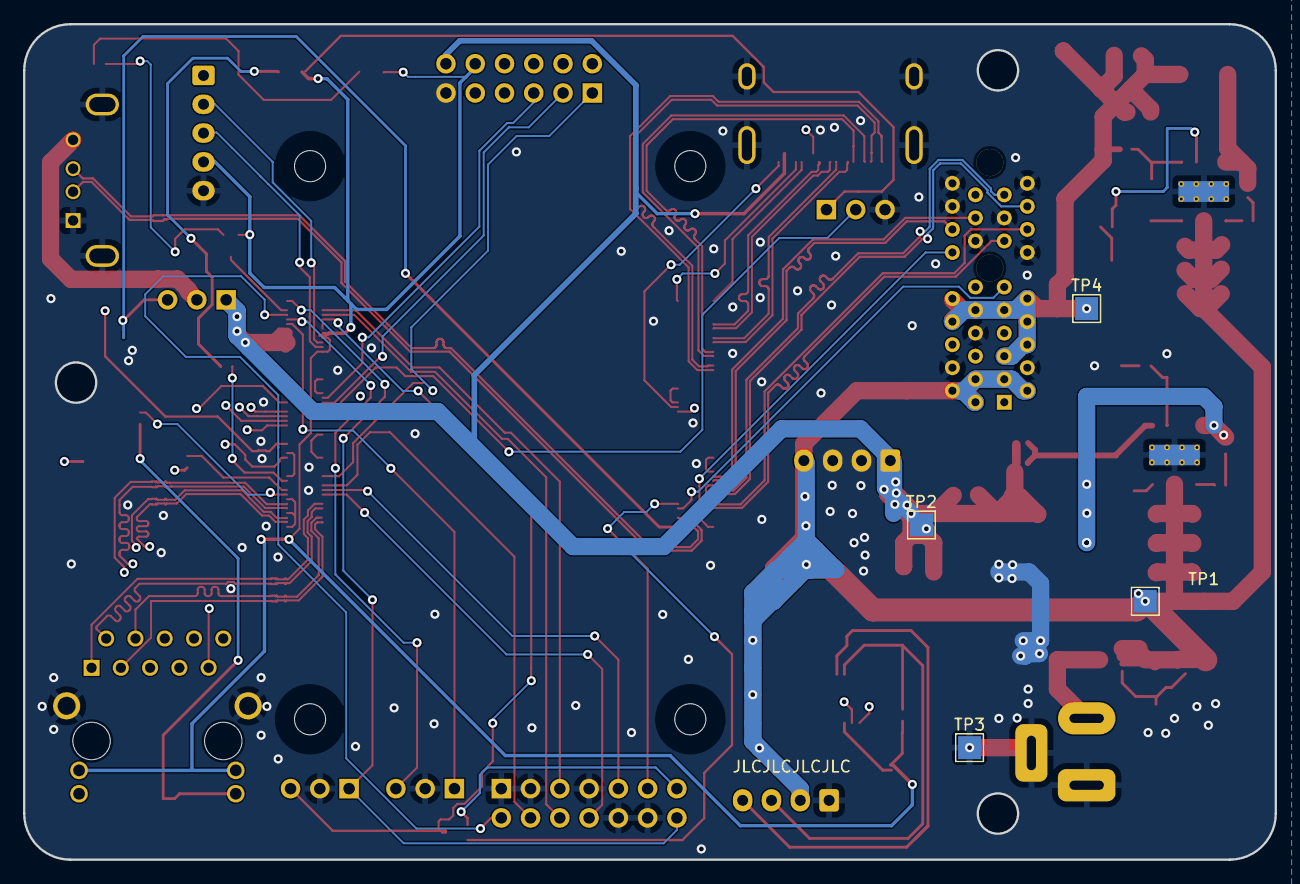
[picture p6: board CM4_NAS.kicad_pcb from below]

Board: 4 copper layers, 108.6 x 72.5 mm, 85 parts (4 on the bottom side), 95 nets.

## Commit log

2024-05-20 Updated to Version 1.5, imported power circuitry for 12V input only
    [BOM NAS).xls, CM4_NAS - コピー.kicad_pcb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]
2024-05-20 Updated README and deleted some stuff
    [CM4_NAS - コピー.kicad_pcb]
2024-05-20 Removed not needed files
    [BOM NAS).xls, Place NAS.xls]
